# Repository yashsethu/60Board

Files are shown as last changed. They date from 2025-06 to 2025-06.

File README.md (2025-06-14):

# 60Board
A low cost, sleek, and custom 60% keyboard!

I made this program for Hack Club's Hackboard (Hackpad) and Highway programs, but moreso to learn more about PCB design! Also, the ducky I use regularly is starting to get a little old, so this would be the perfect replacement! 

Assembly 1 (1)

## Schematic



## PCB



## Bill of Materials (BOM)
| Item | Quantity | Vendor | Total Price |
| :--- | :---: | :----- | ---: |
| Any MX style keyswitches (I used Gateron Milky Yellow Pros) |  64  |  [Kinetic](https://kineticlabs.com/switches/gateron/gateron-milky-yellow-pro-black-bottom-linear) | $16.10 |
| SSD1306 1.9" OLED | 1  | [Amazon](https://www.google.com/search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) | $6.99 |
| Rotary Encoder (preferably short) | 1 | [Aliexpress](https://www.aliexpress.us/item/3256804721655912.html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) | $1.55 | 
| Keycap set (I liked the Soymilk KOA set) | 1 | [Amazon](https://www.amazon.com/dp/B0DGLBXFHD/ref=twister_B0DHWWLTSR?_encoding=UTF8&th=1) | $26.99 |
| Orpheus Pico (or Raspberry Pi Pico 2) | 1 | [Seeed Studio](https://www.seeedstudio.com/Raspberry-Pi-Pico-2-p-5940.html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) | $4.95 |
| Stabilizer set (Generic Keychron) | 1 | [Keychron](https://www.keychron.com/products/keychron-gold-plated-pcb-mounted-stabilizer-set?page=4&gQT=1) | $8.99 |
| Case (Printed) | 1 | My printer | N/A |
| PCB (JLPCB, PCBWay) | 1 | PCBWay (for me) | $82.57 |

**Total Price:** $148.14

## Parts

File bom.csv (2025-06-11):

Item | Quantity | Price
Any MX style keyswitches (I used Gateron Oil Kings) | 64 | $16.10
SSD1306 1.9" OLED | 1 | $6.99
Rotary Encoder (preferably short) | 1 | $1.55
Keycap set (I liked the Soymilk KOA set) | 1 | $26.99
Orpheus Pico (or Raspberry Pi Pico) | 1 | $4.95
Stabilizer set (Generic Gateron) | 1 | $8.99

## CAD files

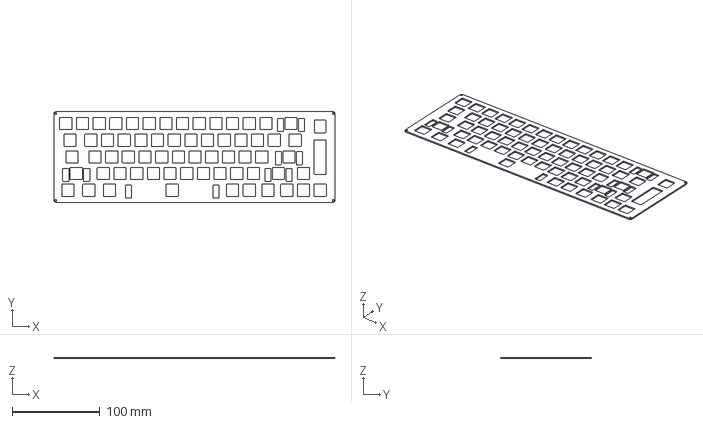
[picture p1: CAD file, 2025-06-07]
Case/keyboard - Plate.step
321.0 x 103.5 x 1.50 mm

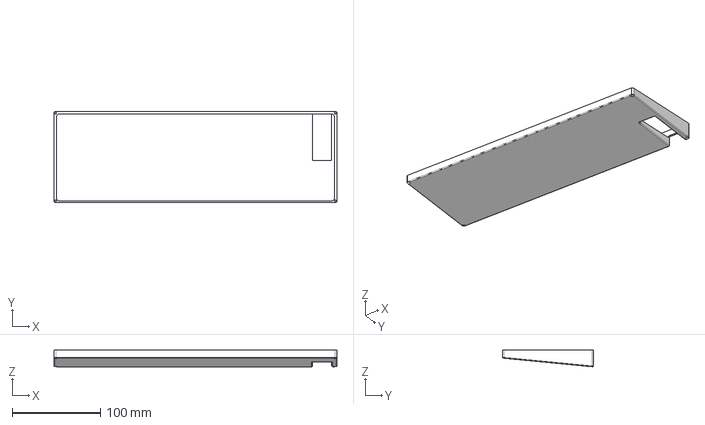
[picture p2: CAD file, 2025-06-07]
Case/keyboard - Bottom.step
321.0 x 103.5 x 18.9 mm

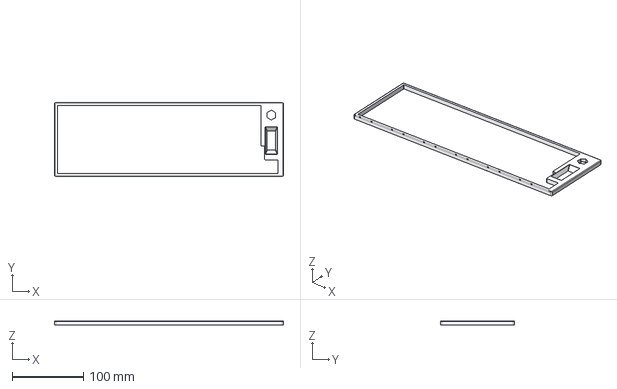
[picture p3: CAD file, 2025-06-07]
Case/keyboard - Top.step
321.0 x 103.5 x 6.00 mm

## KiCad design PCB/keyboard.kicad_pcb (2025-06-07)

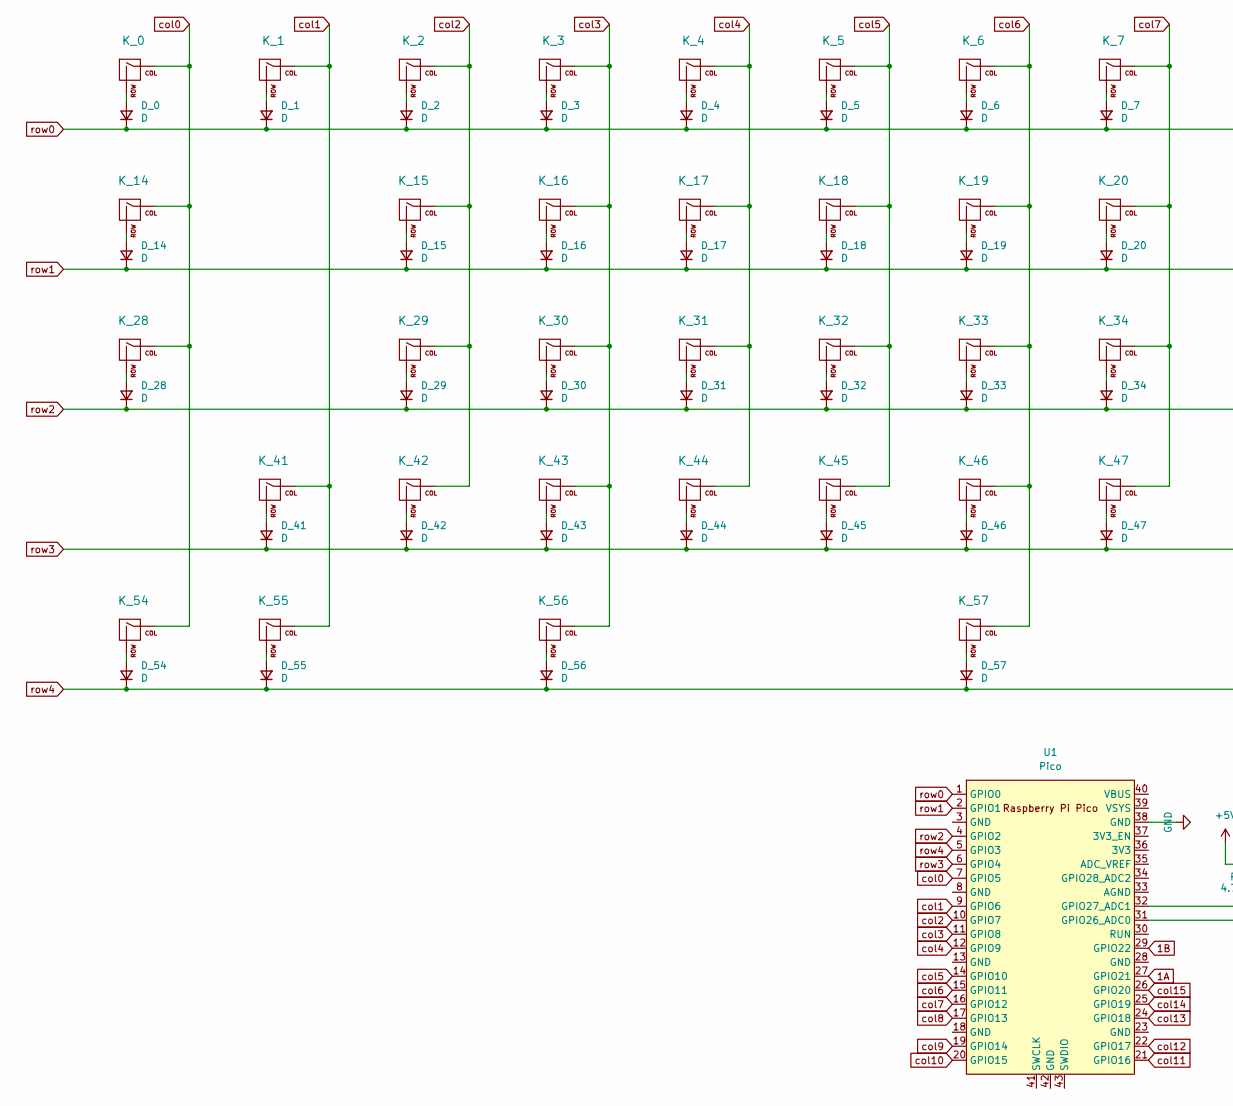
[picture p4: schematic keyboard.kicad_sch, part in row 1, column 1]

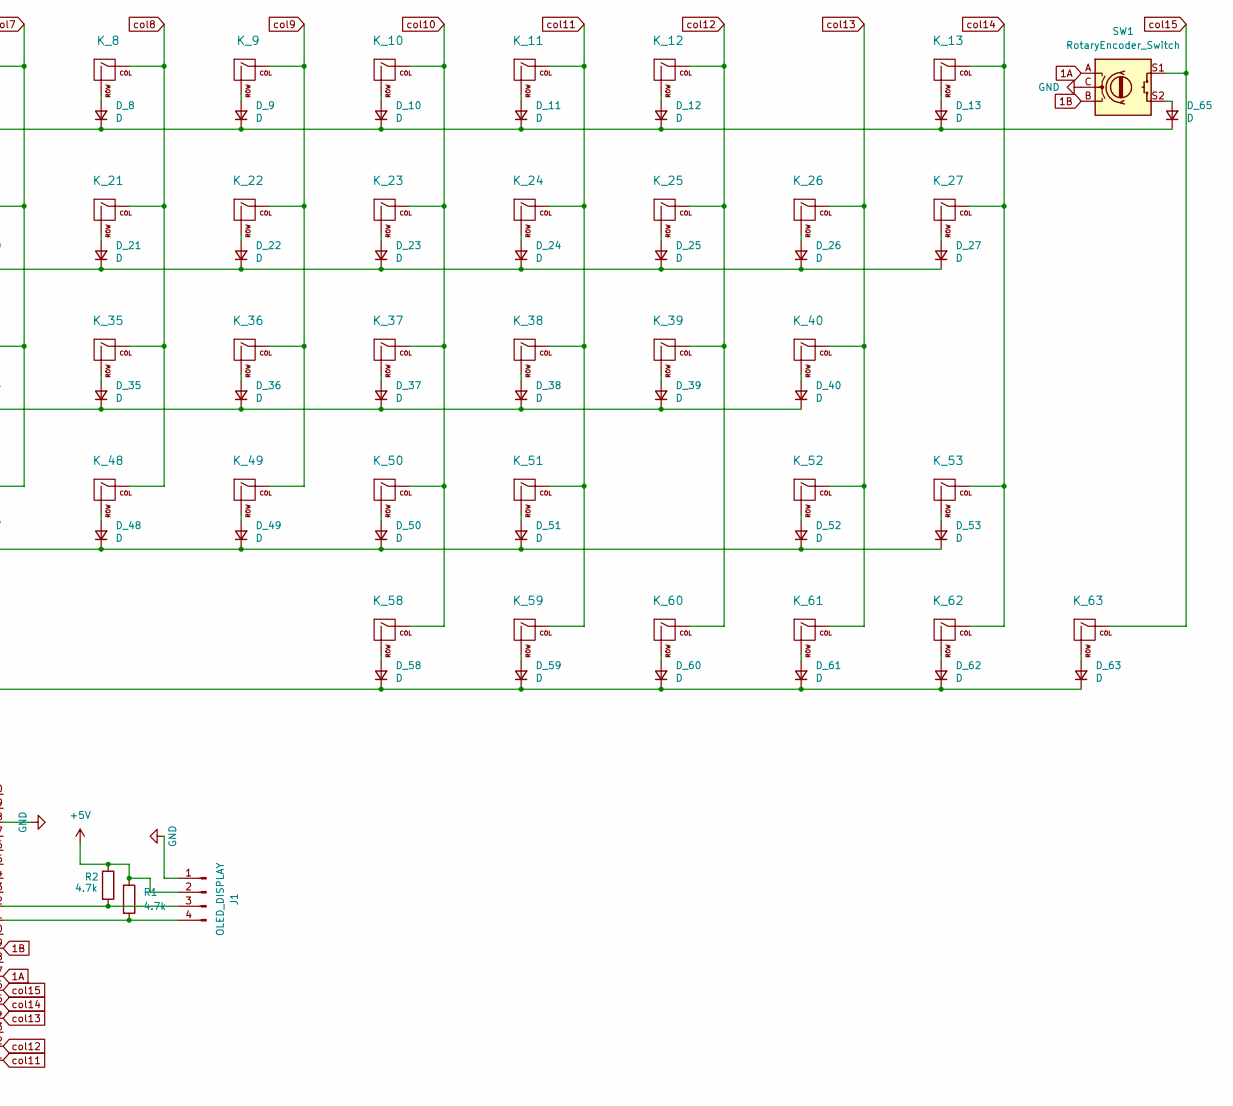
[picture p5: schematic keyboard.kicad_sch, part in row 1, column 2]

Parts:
D_0, D_1, D_2, D_3, D_4, D_5, D_6, D_7, D_8, D_9, D_10, D_11, D_12, D_13, D_14, D_15, D_16, D_17, D_18, D_19, D_20, D_21, D_22, D_23, D_24, D_25, D_26, D_27, D_28, D_29, D_30, D_31, D_32, D_33, D_34, D_35, D_36, D_37, D_38, D_39, D_40, D_41, D_42, D_43, D_44, D_45, D_46, D_47, D_48, D_49, D_50, D_51, D_52, D_53, D_54, D_55, D_56, D_57, D_58, D_59, D_60, D_61, D_62, D_63, D_65: D; D_A-405_P7.62mm_Horizontal
J1: OLED_DISPLAY; 0.91_3D
K_0, K_1, K_2, K_3, K_4, K_5, K_6, K_7, K_8, K_9, K_10, K_11, K_12, K_15, K_16, K_17, K_18, K_19, K_20, K_21, K_22, K_23, K_24, K_25, K_26, K_29, K_30, K_31, K_32, K_33, K_34, K_35, K_36, K_37, K_38, K_39, K_42, K_43, K_44, K_45, K_46, K_47, K_48, K_49, K_50, K_51, K_53, K_58, K_59, K_61, K_62, K_63: KEYSW; SW_Cherry_MX_1.00u_PCB
K_13, K_52: KEYSW; SW_Cherry_MX_2.00u_PCB
K_14, K_27: KEYSW; SW_Cherry_MX_1.50u_PCB
K_28: KEYSW; SW_Cherry_MX_1.75u_PCB
K_40, K_41: KEYSW; SW_Cherry_MX_2.25u_PCB
K_54, K_55, K_56, K_60: KEYSW; SW_Cherry_MX_1.25u_PCB
K_57: KEYSW; SW_Cherry_MX_6.25u_PCB
R1, R2: 4.7k; R_Axial_DIN0204_L3.6mm_D1.6mm_P5.08mm_Horizontal
SW1: RotaryEncoder_Switch; RotaryEncoder_Alps_EC11E-Switch_Vertical_H20mm
U1: Pico; RaspberryPi_Pico_Common_THT

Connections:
1A: SW1.A, U1.27 (GPIO21)
1B: SW1.B, U1.29 (GPIO22)
+5V: J1.2, R1.1, R2.1
GND: J1.1, SW1.C, U1.38 (GND)
unnamed: D_0.2 (A), K_0.2 (ROW)
unnamed: D_1.2 (A), K_1.2 (ROW)
unnamed: D_2.2 (A), K_2.2 (ROW)
unnamed: D_3.2 (A), K_3.2 (ROW)
unnamed: D_4.2 (A), K_4.2 (ROW)
unnamed: D_5.2 (A), K_5.2 (ROW)
unnamed: D_6.2 (A), K_6.2 (ROW)
unnamed: D_7.2 (A), K_7.2 (ROW)
unnamed: D_8.2 (A), K_8.2 (ROW)
unnamed: D_9.2 (A), K_9.2 (ROW)
unnamed: D_10.2 (A), K_10.2 (ROW)
unnamed: D_11.2 (A), K_11.2 (ROW)
unnamed: D_12.2 (A), K_12.2 (ROW)
unnamed: D_13.2 (A), K_13.2 (ROW)
unnamed: D_14.2 (A), K_14.2 (ROW)
unnamed: D_15.2 (A), K_15.2 (ROW)
unnamed: D_16.2 (A), K_16.2 (ROW)
unnamed: D_17.2 (A), K_17.2 (ROW)
unnamed: D_18.2 (A), K_18.2 (ROW)
unnamed: D_19.2 (A), K_19.2 (ROW)
unnamed: D_20.2 (A), K_20.2 (ROW)
unnamed: D_21.2 (A), K_21.2 (ROW)
unnamed: D_22.2 (A), K_22.2 (ROW)
unnamed: D_23.2 (A), K_23.2 (ROW)
unnamed: D_24.2 (A), K_24.2 (ROW)
unnamed: D_25.2 (A), K_25.2 (ROW)
unnamed: D_26.2 (A), K_26.2 (ROW)
unnamed: D_27.2 (A), K_27.2 (ROW)
unnamed: D_28.2 (A), K_28.2 (ROW)
unnamed: D_29.2 (A), K_29.2 (ROW)
unnamed: D_30.2 (A), K_30.2 (ROW)
unnamed: D_31.2 (A), K_31.2 (ROW)
unnamed: D_32.2 (A), K_32.2 (ROW)
unnamed: D_33.2 (A), K_33.2 (ROW)
unnamed: D_34.2 (A), K_34.2 (ROW)
unnamed: D_35.2 (A), K_35.2 (ROW)
unnamed: D_36.2 (A), K_36.2 (ROW)
unnamed: D_37.2 (A), K_37.2 (ROW)
unnamed: D_38.2 (A), K_38.2 (ROW)
unnamed: D_39.2 (A), K_39.2 (ROW)
unnamed: D_40.2 (A), K_40.2 (ROW)
unnamed: D_41.2 (A), K_41.2 (ROW)
unnamed: D_42.2 (A), K_42.2 (ROW)
unnamed: D_43.2 (A), K_43.2 (ROW)
unnamed: D_44.2 (A), K_44.2 (ROW)
unnamed: D_45.2 (A), K_45.2 (ROW)
unnamed: D_46.2 (A), K_46.2 (ROW)
unnamed: D_47.2 (A), K_47.2 (ROW)
unnamed: D_48.2 (A), K_48.2 (ROW)
unnamed: D_49.2 (A), K_49.2 (ROW)
unnamed: D_50.2 (A), K_50.2 (ROW)
unnamed: D_51.2 (A), K_51.2 (ROW)
unnamed: D_52.2 (A), K_52.2 (ROW)
unnamed: D_53.2 (A), K_53.2 (ROW)
unnamed: D_54.2 (A), K_54.2 (ROW)
unnamed: D_55.2 (A), K_55.2 (ROW)
unnamed: D_56.2 (A), K_56.2 (ROW)
unnamed: D_57.2 (A), K_57.2 (ROW)
unnamed: D_58.2 (A), K_58.2 (ROW)
unnamed: D_59.2 (A), K_59.2 (ROW)
unnamed: D_60.2 (A), K_60.2 (ROW)
unnamed: D_61.2 (A), K_61.2 (ROW)
unnamed: D_62.2 (A), K_62.2 (ROW)
unnamed: D_63.2 (A), K_63.2 (ROW)
unnamed: D_65.2 (A), SW1.S2
unnamed: J1.3, R2.2, U1.32 (GPIO27_ADC1)
unnamed: J1.4, R1.2, U1.31 (GPIO26_ADC0)
col0: K_0.1 (COL), K_14.1 (COL), K_28.1 (COL), K_54.1 (COL), U1.7 (GPIO5)
col1: K_1.1 (COL), K_41.1 (COL), K_55.1 (COL), U1.9 (GPIO6)
col2: K_2.1 (COL), K_15.1 (COL), K_29.1 (COL), K_42.1 (COL), U1.10 (GPIO7)
col3: K_3.1 (COL), K_16.1 (COL), K_30.1 (COL), K_43.1 (COL), K_56.1 (COL), U1.11 (GPIO8)
col4: K_4.1 (COL), K_17.1 (COL), K_31.1 (COL), K_44.1 (COL), U1.12 (GPIO9)
col5: K_5.1 (COL), K_18.1 (COL), K_32.1 (COL), K_45.1 (COL), U1.14 (GPIO10)
col6: K_6.1 (COL), K_19.1 (COL), K_33.1 (COL), K_46.1 (COL), K_57.1 (COL), U1.15 (GPIO11)
col7: K_7.1 (COL), K_20.1 (COL), K_34.1 (COL), K_47.1 (COL), U1.16 (GPIO12)
col8: K_8.1 (COL), K_21.1 (COL), K_35.1 (COL), K_48.1 (COL), U1.17 (GPIO13)
col9: K_9.1 (COL), K_22.1 (COL), K_36.1 (COL), K_49.1 (COL), U1.19 (GPIO14)
col10: K_10.1 (COL), K_23.1 (COL), K_37.1 (COL), K_50.1 (COL), K_58.1 (COL), U1.20 (GPIO15)
col11: K_11.1 (COL), K_24.1 (COL), K_38.1 (COL), K_51.1 (COL), K_59.1 (COL), U1.21 (GPIO16)
col12: K_12.1 (COL), K_25.1 (COL), K_39.1 (COL), K_60.1 (COL), U1.22 (GPIO17)
col13: K_26.1 (COL), K_40.1 (COL), K_52.1 (COL), K_61.1 (COL), U1.24 (GPIO18)
col14: K_13.1 (COL), K_27.1 (COL), K_53.1 (COL), K_62.1 (COL), U1.25 (GPIO19)
col15: K_63.1 (COL), SW1.S1, U1.26 (GPIO20)
row0: D_0.1 (K), D_1.1 (K), D_2.1 (K), D_3.1 (K), D_4.1 (K), D_5.1 (K), D_6.1 (K), D_7.1 (K), D_8.1 (K), D_9.1 (K), D_10.1 (K), D_11.1 (K), D_12.1 (K), D_13.1 (K), D_65.1 (K), U1.1 (GPIO0)
row1: D_14.1 (K), D_15.1 (K), D_16.1 (K), D_17.1 (K), D_18.1 (K), D_19.1 (K), D_20.1 (K), D_21.1 (K), D_22.1 (K), D_23.1 (K), D_24.1 (K), D_25.1 (K), D_26.1 (K), D_27.1 (K), U1.2 (GPIO1)
row2: D_28.1 (K), D_29.1 (K), D_30.1 (K), D_31.1 (K), D_32.1 (K), D_33.1 (K), D_34.1 (K), D_35.1 (K), D_36.1 (K), D_37.1 (K), D_38.1 (K), D_39.1 (K), D_40.1 (K), U1.4 (GPIO2)
row3: D_41.1 (K), D_42.1 (K), D_43.1 (K), D_44.1 (K), D_45.1 (K), D_46.1 (K), D_47.1 (K), D_48.1 (K), D_49.1 (K), D_50.1 (K), D_51.1 (K), D_52.1 (K), D_53.1 (K), U1.6 (GPIO4)
row4: D_54.1 (K), D_55.1 (K), D_56.1 (K), D_57.1 (K), D_58.1 (K), D_59.1 (K), D_60.1 (K), D_61.1 (K), D_62.1 (K), D_63.1 (K), U1.5 (GPIO3)

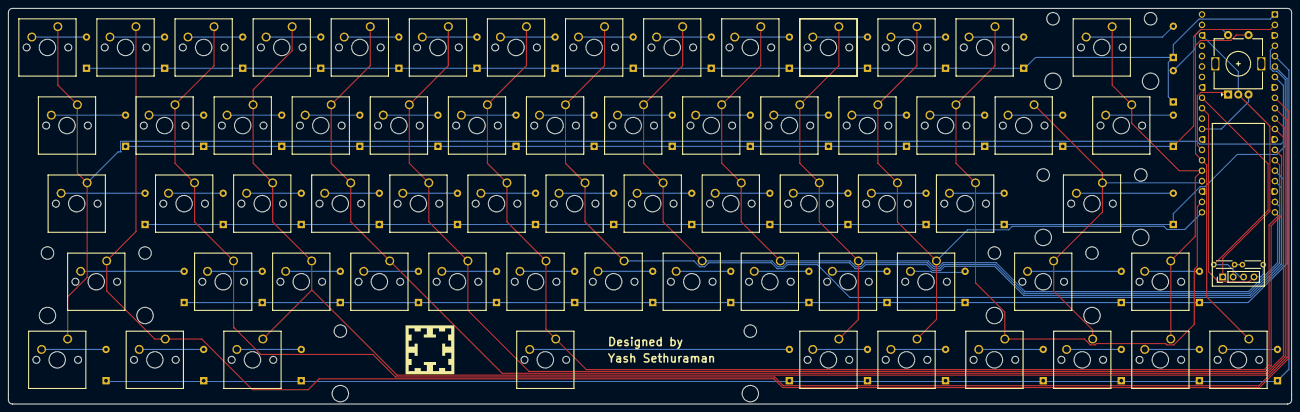
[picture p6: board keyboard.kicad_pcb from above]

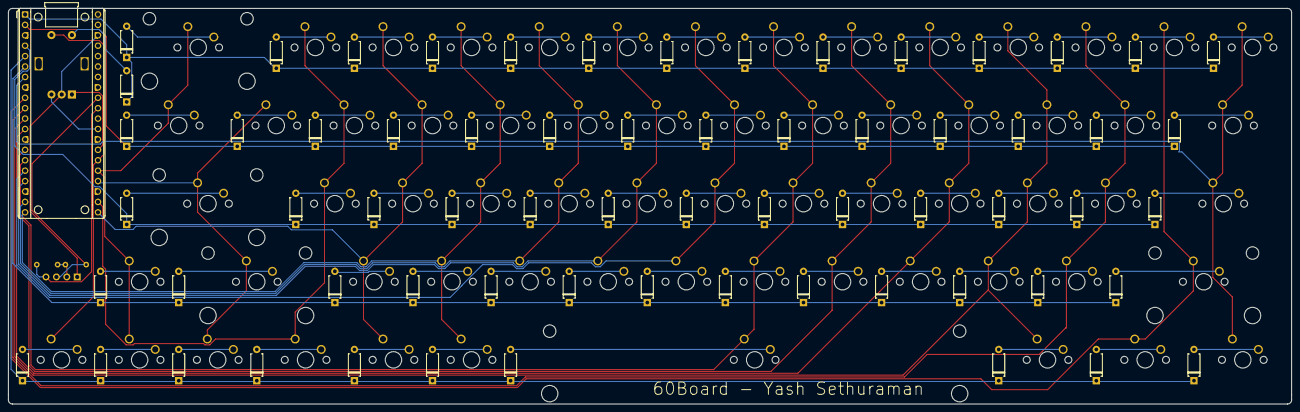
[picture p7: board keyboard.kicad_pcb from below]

Board: 2 copper layers, 313.0 x 96.5 mm, 134 parts (66 on the bottom side), 92 nets.

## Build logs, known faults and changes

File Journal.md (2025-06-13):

# Design Journal

I started designing 60Board with the key layout. Using a cool tool called the [Keyboard Layout Editor](https://www.keyboard-layout-editor.com/), I made a nice 60% layout with enough space.

Total time: 30 hrs



Notice that I left enough space on the right for a display, along with the "Insert" key as a placeholder for a rotary encoder later on. 

The reason I used this tool is so that I could get this very important raw data: 
```
["~\n`","!\n1","@\n2","#\n3","$\n4","%\n5","^\n6","&\n7","*\n8","(\n9",")\n0","_\n-","+\n=",{w:2},"Backspace",{x:0.5},"Insert"],
[{w:1.5},"Tab","Q","W","E","R","T","Y","U","I","O","P","{\n[","}\n]",{w:1.5},"|\n\\"],
[{w:1.75},"Caps Lock","A","S","D","F","G","H","J","K","L",":\n;","\"\n'",{w:2.25},"Enter"],
[{w:2.25},"Shift","Z","X","C","V","B","N","M","<\n,",">\n.","?\n/",{w:2.25},"Shift","↑"],
[{w:1.25},"Ctrl","Win",{w:1.25},"Alt",{a:7,w:6.25},"",{a:4,w:1.25},"Alt",{w:1.25},"Ctrl",{w:1.25},"Menu","←","↓","→"]
```

Then, I fed that data into a [keyboard schematic generator](https://kb.xyz.is/) to make my job a little easier. 
**However**, this isn't a full workflow, since the schematic and PCB generated use the wrong key footprints, SMD components, and don't have the microcontroller yet. It's not as easy as it seems!



## Schematic: 5 hrs (6/4/25)
Alright, so we can finally move on to the actual keyboard development, starting with the schematic. 

The easiest part first, the key layout:


Notes:
- The grid of keys were provided by the generator, but I had to remake the labels for readability (Rw1 -> Row 1), along with rewiring the last four rows. Generators aren't perfect!
- A rotary encoder switch (meaning that pressing down on the knob can trigger actions) has been added to the right hand side

The row numbers I provided earlier were crucial, because it makes wiring the actual microcontroller so much easier. 



Notes:
- The rows and columns are assigned with great detail to ensure PCB routing is easy. That means that I ensured that the higher rows were assigned to GPIO pins higher up on the microcontroller, and ensured rows side by side were assigned appropriate pins
- An OLED display has been added, with a 4-pin header as a placeholder. The outputs have been respectively pulled up with THT resistors.

## PCB: 15 hrs (6/7/25)
The PCB will be significantly harder, so let's get started!

Instantly, when booting up the PCB from the generator, we notice a few things wrong:
- The board is missing an outline
- The keyswitch footprints are clearly wrong
- The PCB uses SMD diodes
- There are no stabilizers
- There is no keyswitch CAD, so 3D view does not display a keyboard (yet)





### Process
1. With a little ingenuity with KiCad, we can select all and filter the objects to only the switches, and replace each type of switch (size) with our Cherry-MX style footprint. 

2. This same process is then applied to replace all the SMD diodes with THT diodes. I used the move by coordinates tool to move them perfectly to the left of each switch.

3. Now, we add in the microcontroller, rotary encoder, and OLED display. I oriented them to save the most space, fitting the resistors under the OLED itself and integrating the microcontroller with both, making life easier



4. Routing time! This takes a LOT of time, so no rush! I made absolutely sure to make it as appealing and space saving as possible, with **no vias at all!**





5. Time to add some aesthetics! I added a cool symbol and my name to the board



6. CAD: I painstakingly found every single CAD model for all the stabilizers, switches, and other components, and added them to my KICAD library. Then, they had to be properly oriented within the existing CAD models. Here's the result:



Notice these details:
- Both keyswitches and stabilizers have been added, with detail to the type and Cherry-MX style
- Microcontroller, OLED display, resistor CAD has been added in
- Rotary encoder has been added, with detail to what height encoder I plan to buy

My PCB is finally done! Now, I can get to designing the case. 

## Case: 10 hrs (6/9/25)
The case of the 60Board is arguably the most well thought out. It has been optimized into a 3-part, sandwich mount style with heat-press inserts, along with significant detail to tolerances along with an angled bottom for ergonomics. 

I started with the plate of the keyboard. Using Onshape's project tool and some ingenuity with dimensions, this was fairly simple.



After extruding those, I was able to use the same sketch for the top, with this as a result:



Then, I used a very careful approach to make the bottom, fitting with the board perfectly





With a few chamfers and fillets, my case is done!



## Firmware
Since QMK makes it so easy, I will spare explaining every bit of firmware, but I used the SSD1306 driver within the code to make the OLED work. Pretty cool!

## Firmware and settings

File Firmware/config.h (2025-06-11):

// Copyright 2023 QMK
// SPDX-License-Identifier: GPL-2.0-or-later

#define ENCODER_A_PINS {GP0}
#define ENCODER_B_PINS {GP1}

#define I2C_DRIVER I2CD1
#define I2C1_SDA_PIN GP6
#define I2C1_SCL_PIN GP7
